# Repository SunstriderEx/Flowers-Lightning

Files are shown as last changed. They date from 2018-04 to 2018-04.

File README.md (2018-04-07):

# Подсветка растений
Умный светильник для комнатных растений и desktop-приложение для настройки устройства по USB.

Яркость светильника зависит от внешнего освещения, чем оно ярче, тем слабее он светит, поддерживая тем самым необходимый минимальный уровень освещённости.

## Подробности
Основной элемент - STM32 Minimum system development board.

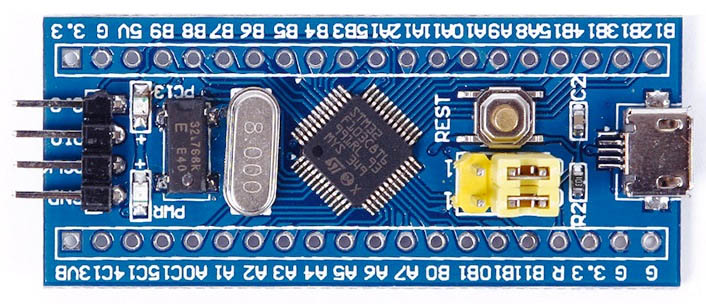
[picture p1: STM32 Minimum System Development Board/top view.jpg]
Внешний вид


На её борту имеется часовой кварцевый резонатор, что избавляет от необходимости отдельной установки данного компонента для работы RTC.

Для работы устройства необходим внешний блок питания на 12В и ток не менее 1А.

Использованный дроссель вводит ограничение на ток, протекающий через источник(и) света. В моём случае он составил около 1А. Хотя этот компонент является необязательным, так как пульсации на частоте 30 кГц незначительны.

В качестве датчика освещённости используется фоторезистор GL5528. Для регулировки зависимости яркости от внешнего освещения в устройстве присутствует подстроечный резистор.

Для настройки устройства используется приложение под Windows, позволяющее синхронизировать время часов и указывать время сна. Интерфейс связи - USB. Скриншот программы:

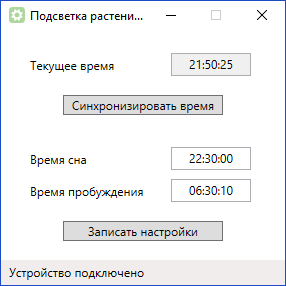
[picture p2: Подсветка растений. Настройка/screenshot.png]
Скриншот программы


При входе и выходе из режима сна яркость понижается или повышается медленно и плавно.

Для ручного перевода светильника в режим сна имеется соответствующая кнопка (устройство "проснётся" по графику).

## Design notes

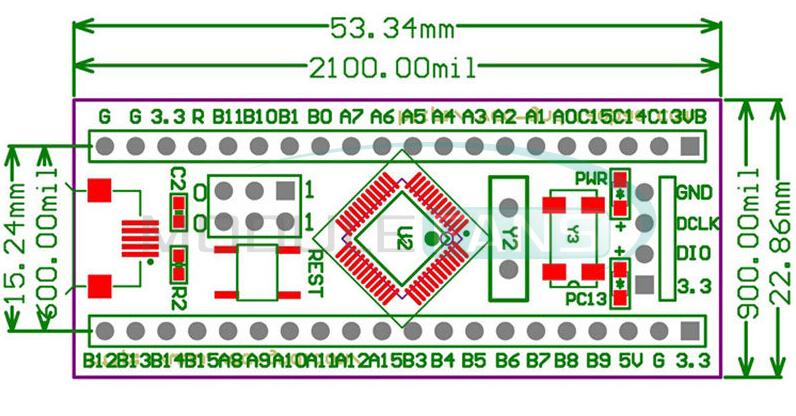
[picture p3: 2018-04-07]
STM32 Minimum System Development Board/dimensions.jpg

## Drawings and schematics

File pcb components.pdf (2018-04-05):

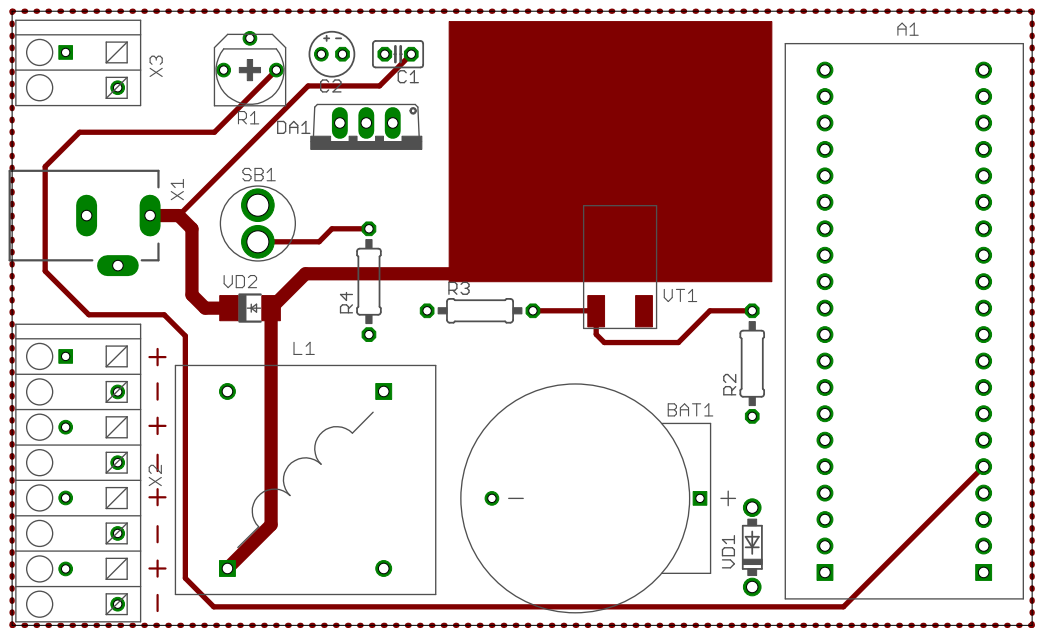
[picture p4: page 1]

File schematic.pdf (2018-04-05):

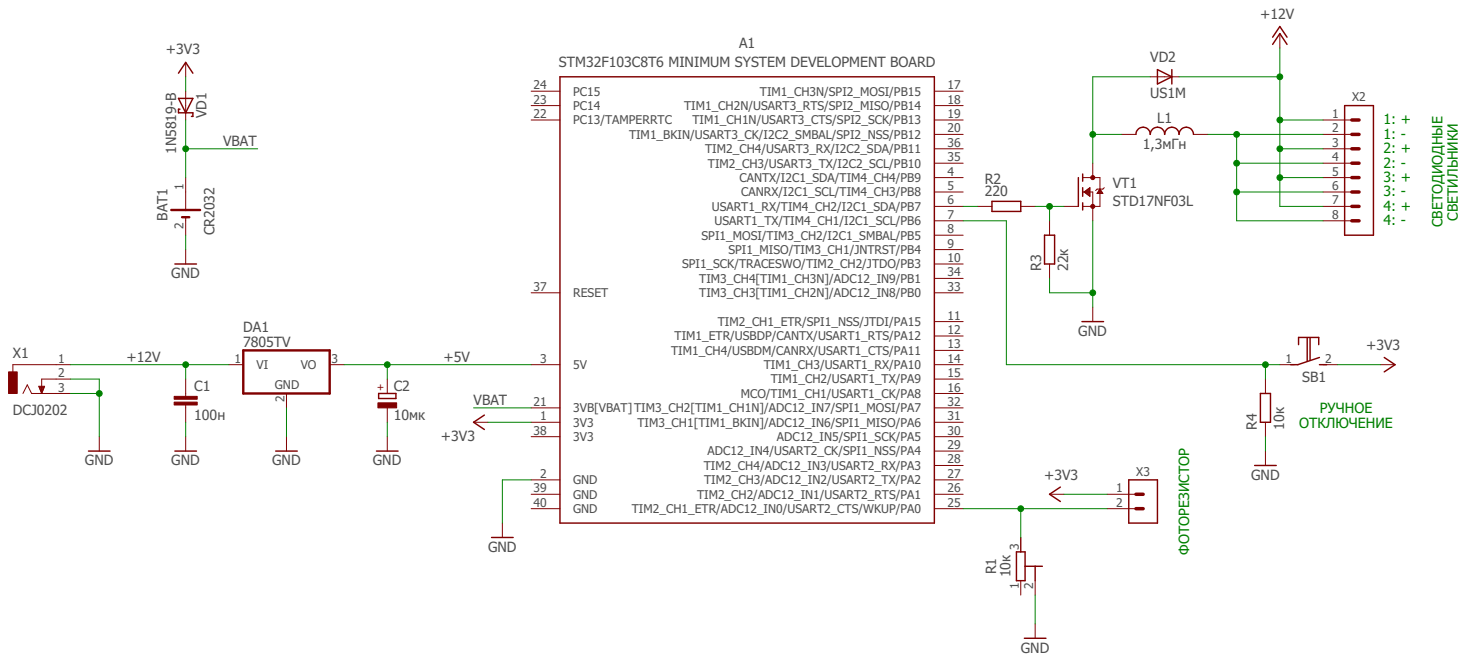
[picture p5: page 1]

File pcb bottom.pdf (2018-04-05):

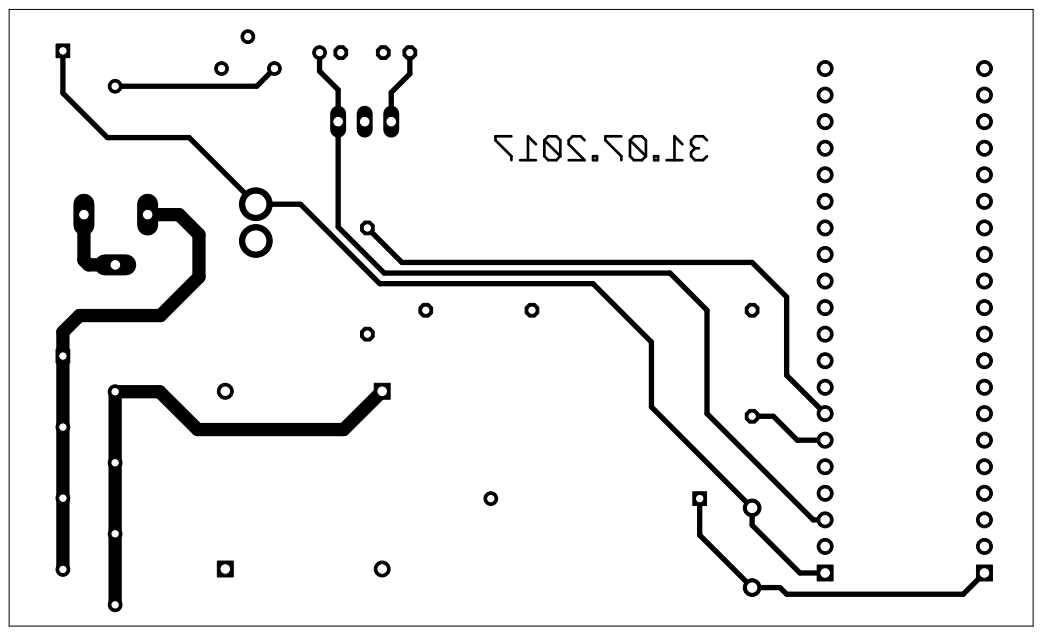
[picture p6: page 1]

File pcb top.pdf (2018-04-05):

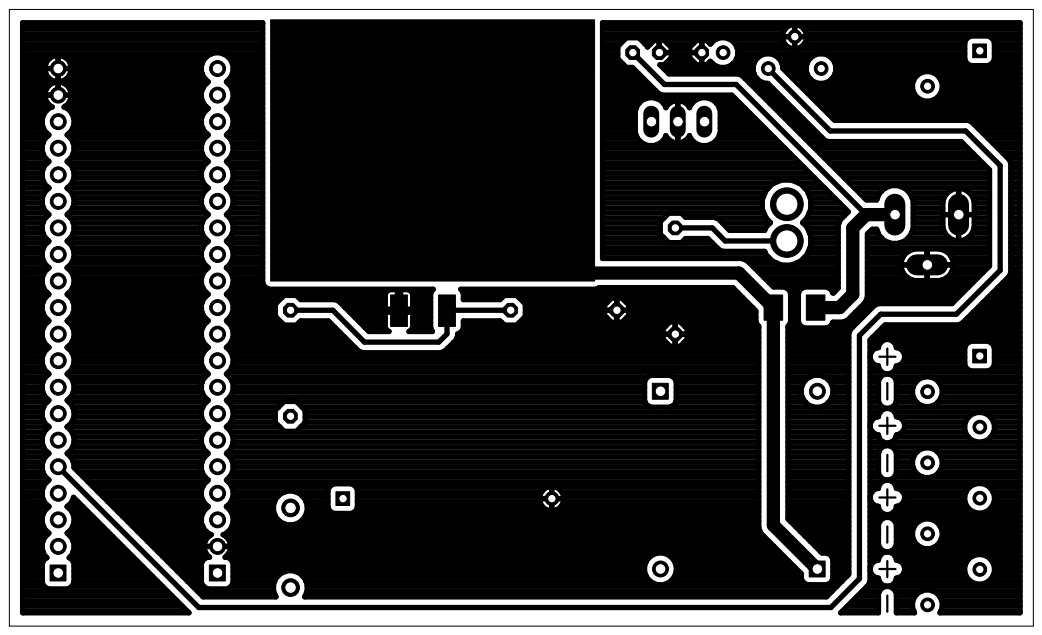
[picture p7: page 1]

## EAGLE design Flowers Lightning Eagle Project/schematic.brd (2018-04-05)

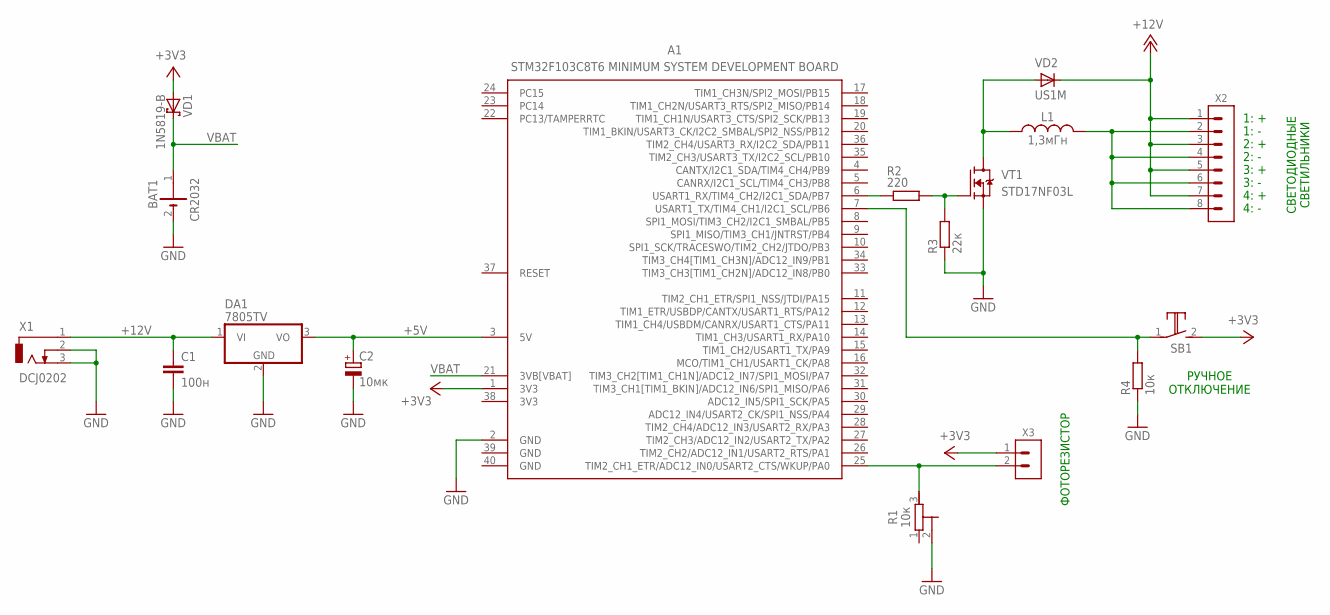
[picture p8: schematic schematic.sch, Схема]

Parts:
A1: STM32F103C8T6_MINIMUM_SYSTEM_DEVELOPMENT_BOARD
BAT1: CR2032; CR2032HOLDER
C1: 100н; C025-025X050
C2: 10мк; E2-4
DA1: 7805TV; TO220V
L1: 1,3мГн; INDUCTOR-2.5MH
R1: 10к; TRIMMER
R2: 220; 0207/10
R3: 22к; 0207/10
R4: 10к; 0207/10
SB1: PBS-10B-2
VD1: 1N5819-B; DO41-7.6
VD2: US1M; DO-214AC
VT1: STD17NF03L; DPAK
X1: DCJ0202
X2: TERMINALS_BLOCK_8PIN
X3: TERMINALS_BLOCK_2PIN

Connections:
3V3: A1.38 (3V3)
+3V3: A1.1 (3V3), SB1.2 (NO), VD1.A, X3.1
+5V: A1.3 (5V), C2.+, DA1.3 (VO)
+12V: C1.1, DA1.1 (VI), VD2.C, X1.1, X2.1, X2.3, X2.5, X2.7
DRAIN: L1.1, VD2.A, VT1.D
GND: A1.2 (GND), A1.39 (GND), A1.40 (GND), BAT1.2 (-), C1.2, C2.-, DA1.2 (GND), R1.2 (S), R3.1, R4.1, VT1.S, X1.2, X1.3
unnamed: A1.7 (USART1_TX/TIM4_CH1/I2C1_SCL/PB6), R4.2, SB1.1 (COM)
unnamed: R2.2, R3.2, VT1.G
unnamed: L1.2, X2.2, X2.4, X2.6, X2.8
unnamed: A1.25 (TIM2_CH1_ETR/ADC12_IN0/USART2_CTS/WKUP/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), R1.3 (E), X3.2
unnamed: A1.6 (USART1_RX/TIM4_CH2/I2C1_SDA/PB7), R2.1
VBAT: A1.21 (3VB[VBAT]), BAT1.1 (+), VD1.C

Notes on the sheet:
ФОТОРЕЗИСТОР
СВЕТОДИОДНЫЕ СВЕТИЛЬНИКИ
1: +
1: -
2: +
2: -
3: +
3: -
4: +
4: -
РУЧНОЕ ОТКЛЮЧЕНИЕ

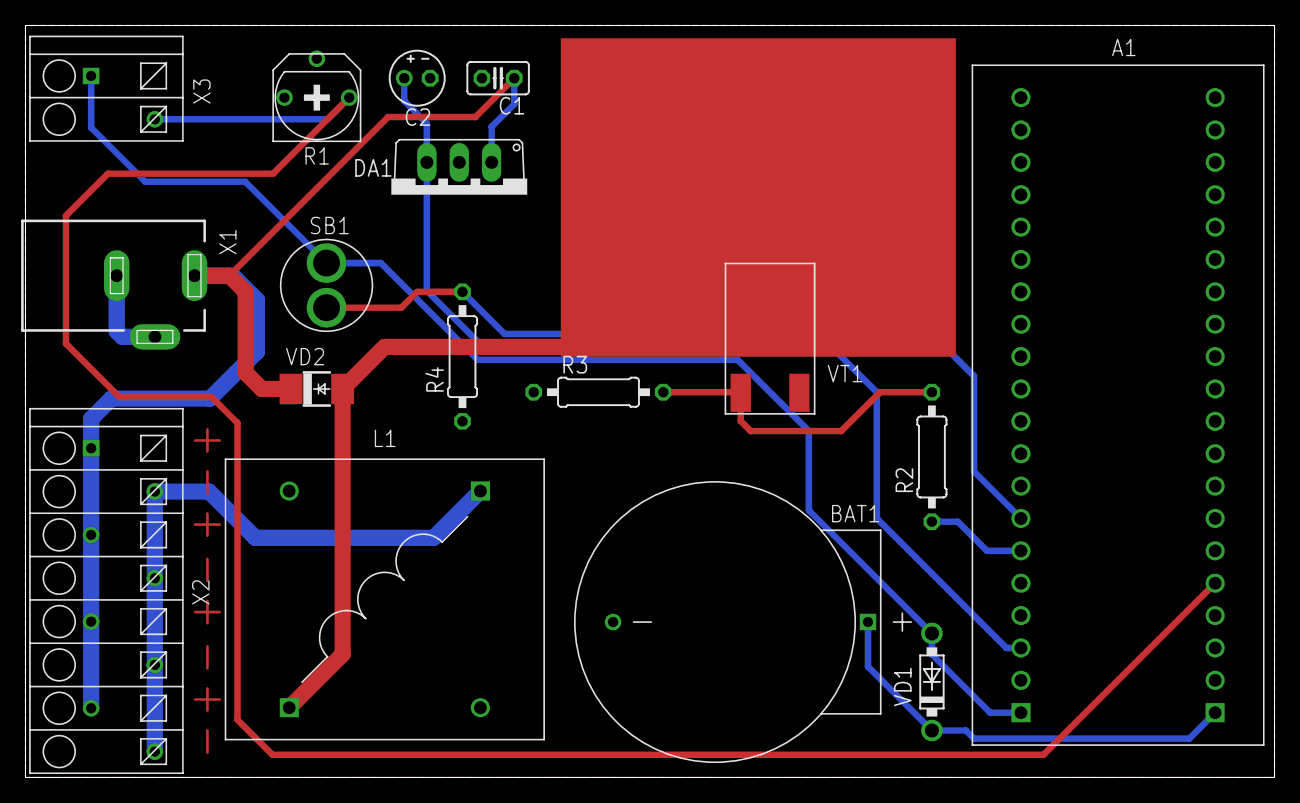
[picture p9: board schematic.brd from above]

Board: 2 copper layers, 98.0 x 59.0 mm, 17 parts (0 on the bottom side), 11 nets.

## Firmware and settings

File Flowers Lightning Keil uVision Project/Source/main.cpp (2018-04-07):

#include "stm32f10x.h"
#include "stm32f10x_gpio.h"
#include "stm32f10x_rcc.h"
#include "stm32f10x_usart.h"
#include "misc.h"

#include "adc.h"
#include "pwm.h"
#include "rtc.h"
#include "supply.h"
#include "usart.h"
#include "timing.h"
#include "usb hid.h"
#include "flash.h"

#include <math.h>
#include <stdio.h>

void SetSysClockTo72()
{
    ErrorStatus HSEStartUpStatus;
    /* SYSCLK, HCLK, PCLK2 and PCLK1 configuration -----------------------------*/
    /* RCC system reset(for debug purpose) */
    RCC_DeInit();
 
    /* Enable HSE */
    RCC_HSEConfig(RCC_HSE_ON);
 
    /* Wait till HSE is ready */
    HSEStartUpStatus = RCC_WaitForHSEStartUp();
 
    if (HSEStartUpStatus == SUCCESS)
    {
        /* Enable Prefetch Buffer */
        //FLASH_PrefetchBufferCmd( FLASH_PrefetchBuffer_Enable);
 
        /* Flash 2 wait state */
        //FLASH_SetLatency( FLASH_Latency_2);
 
        /* HCLK = SYSCLK */
        RCC_HCLKConfig(RCC_SYSCLK_Div1);
 
        /* PCLK2 = HCLK */
        RCC_PCLK2Config(RCC_HCLK_Div1);
 
        /* PCLK1 = HCLK/2 */
        RCC_PCLK1Config(RCC_HCLK_Div1);
 
        /* PLLCLK = 8MHz * 9 = 72 MHz */
        RCC_PLLConfig(0x00010000, RCC_PLLMul_9);
 
        /* Enable PLL */
        RCC_PLLCmd(ENABLE);
 
        /* Wait till PLL is ready */
        while (RCC_GetFlagStatus(RCC_FLAG_PLLRDY) == RESET)
        {
        }
 
        /* Select PLL as system clock source */
        RCC_SYSCLKConfig(RCC_SYSCLKSource_PLLCLK);
 
        /* Wait till PLL is used as system clock source */
        while (RCC_GetSYSCLKSource() != 0x08)
        {
        }
    }
    else
    { /* If HSE fails to start-up, the application will have wrong clock configuration.
     User can add here some code to deal with this error */
 
        /* Go to infinite loop */
        while (1)
        {
        }
    }
}

void Init()
{
    SetSysClockTo72();
    Timing::InitSysTickTimer();
    
    RCC_APB2PeriphClockCmd(RCC_APB2Periph_GPIOA, ENABLE); // Enable GPIOA clocking
    RCC_APB2PeriphClockCmd(RCC_APB2Periph_GPIOB, ENABLE); // Enable GPIOB clocking
    
    GPIO_InitTypeDef port;
    GPIO_StructInit(&port);
    port.GPIO_Mode = GPIO_Mode_IPD;
    port.GPIO_Pin = GPIO_Pin_6;
    port.GPIO_Speed = GPIO_Speed_2MHz;
    GPIO_Init(GPIOB, &port);
}

float ldrValue;
float duty = 1;

int main()
{
    Init();

    // Initialize USART
    //USART::Init();
    //USART::USARTSend((const unsigned char*)"Hello.\r\nUSART1 is ready.\r\n");
    USB_HID::Init(); // нужно инициализировать до RTCModule::Init(), иначе задержка не даст копму получить дескриптор
                     // (при подключении по USB без батарейки в устройстве, вероятно)    
    Flash::Init();
    
    ADC::Init();
    ADC::Calibrate();
    ADC::StartReading();
    
    PWM::Init();
    PWM::Enable();
 
    unsigned int RTC_Counter;
    unsigned int RTC_Counter_TimeToSleep;
    unsigned int RTC_Counter_TimeToAwake;
    RTC_TimeTypeDef RTC_Time;
    if (RTCModule::Init() == 1)
    {
        // После инициализации требуется задержка. Без нее время не устанавливается.
        osDelay(100);//for (int i = 0; i < 1000000; i++) { } //delay_ms(500);
        // Если первая инициализация RTC устанавливаем начальное время
        RTC_Time.hours = 15;
        RTC_Time.minutes = 29;
        RTC_Time.seconds = 55;
        RTC_SetCounter(RTCModule::TimeToCounter(&RTC_Time));
    }
    // Считаем настройки времени из Flash памяти
    Flash::ReadSettings();
    
    // usart
    //char buffer[80] = {'\0'};
    unsigned int lastRTC_Counter = 0;
    
    while (1)
    {
        // Real Time Clock
        RTC_Counter = RTC_GetCounter();
        RTCModule::CounterToTime(RTC_Counter, &RTC_Time);
        // Reset RTC every day
        if (RTC_Counter >= RTCModule::CounterToResetRTC)
        {
            RTCModule::ResetRTC();
            RTC_Counter = RTC_GetCounter();
            RTCModule::CounterToTime(RTC_Counter, &RTC_Time);
        }
        
        // Sleeping Mode
        RTC_Counter_TimeToSleep = RTCModule::TimeToCounter((RTC_TimeTypeDef*)(&RTCModule::TimeToSleep));
        RTC_Counter_TimeToAwake = RTCModule::TimeToCounter((RTC_TimeTypeDef*)(&RTCModule::TimeToAwake));
        if ((RTC_Counter >= RTC_Counter_TimeToSleep && RTC_Counter < RTC_Counter_TimeToAwake && RTC_Counter_TimeToAwake > RTC_Counter_TimeToSleep)
            || ((RTC_Counter >= RTC_Counter_TimeToSleep || RTC_Counter < RTC_Counter_TimeToAwake) && RTC_Counter_TimeToAwake < RTC_Counter_TimeToSleep))
        {
            
            if (!Supply::SleepingModeIsActive())
            {
                PWM::fadingModeIsActive = true; // плавное затухание
                Supply::StartSleepingMode(false);
            }
            else if (Supply::SleepingModeIsForced()) // если в сон вошли кнопкой, то сбрасываем флаг forcedSleepingMode, 
                Supply::StartSleepingMode(false);    // чтобы [утром] автоматически выйти из режима сна (проснуться)
        }
        else
        {
            if (Supply::SleepingModeIsActive() && !Supply::SleepingModeIsForced())
                Supply::AwakeFromSleepingMode();
        }
        
        // Force Sleeping Mode button
        Supply::CheckSleepingModeButton();
        
        // PWM
        if (!Supply::SleepingModeIsActive())
        {
            ldrValue = ADC::GetPhotoresistorValue(); // LDR (Light Dependent Resistor) = Photoresistor
            duty = powf((ldrValue / (4096 - 1)), 0.5); //, 0.25);
            PWM::UpdateDuty(duty);
        }
        else if (PWM::fadingModeIsActive)
        {
            // плавное затухание
            duty += 0.0000005;
            PWM::UpdateDuty(duty);
            if (duty > PWM::dimThreshold)
                Supply::StartSleepingMode(true); // окончательный сон
        }
        
        // USART and USB
        //USB_HID::CheckUSBConnection();
        //sprintf(buffer, "ldrValue = %d, duty = %f\r\n", ldrValue, duty);
        if (Timing::Millis() - lastRTC_Counter >= 200) //if (lastRTC_Counter != RTC_Counter)
        {
            //sprintf(buffer, "counter = %d, Time = %d:%d:%d, millis = %d\r\n", RTC_Counter, RTC_Time.hours, RTC_Time.minutes, RTC_Time.seconds, Timing::Millis());
            //USART::USARTSend((unsigned char*)buffer);
            
            //sprintf(buffer, "%d:%d:%d", RTC_Time.hours, RTC_Time.minutes, RTC_Time.seconds);
            //USBD_HID_GetReportTrigger(0, USB_HID::DeviceRtcTime, (const uint8_t*)(&buffer), sizeof(buffer));
            USB_HID::SendSettings();
            
            lastRTC_Counter = Timing::Millis(); //RTC_Counter;
        }
        
        // Save settings if needed
        Flash::WriteSettingsIfNeeded();
    }
}

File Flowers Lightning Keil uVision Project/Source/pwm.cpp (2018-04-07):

#include "pwm.h"

const float PWM::brightThreshold = 0.001;
const float PWM::dimThreshold = 0.999;
bool PWM::fadingModeIsActive;

extern "C" void TIM3_IRQHandler()
{
    if (TIM_GetITStatus(TIM3, TIM_IT_Update) != RESET)
    {
        TIM_ClearITPendingBit(TIM3, TIM_IT_Update);
        
        GPIOC->ODR ^= GPIO_Pin_13;
    }
}

void PWM::Init()
{
    RCC_APB1PeriphClockCmd(RCC_APB1Periph_TIM4, ENABLE);  // Enable TIM4 clocking
    
    GPIO_InitTypeDef port;
    TIM_TimeBaseInitTypeDef timer;
    TIM_OCInitTypeDef timerPWM;
 
    GPIO_StructInit(&port);
    port.GPIO_Mode = GPIO_Mode_AF_PP;
    port.GPIO_Pin = GPIO_Pin_7; // pin PB7
    port.GPIO_Speed = GPIO_Speed_2MHz;
    GPIO_Init(GPIOB, &port);
 
    TIM_TimeBaseStructInit(&timer);
    timer.TIM_Prescaler = 0;
    timer.TIM_Period = Period;
    timer.TIM_ClockDivision = 0; //TIM_CKD_DIV1;
    timer.TIM_CounterMode = TIM_CounterMode_Up;
    TIM_TimeBaseInit(TIM4, &timer);
 
    TIM_OCStructInit(&timerPWM);
    // PWM mode 2 = Clear on compare match
    // PWM mode 1 = Set on compare match
    timerPWM.TIM_OCMode = TIM_OCMode_PWM2;
    timerPWM.TIM_OutputState = TIM_OutputState_Enable;
    timerPWM.TIM_Pulse = Period - 1;
    timerPWM.TIM_OCPolarity = TIM_OCPolarity_High;
    TIM_OC2Init(TIM4, &timerPWM);
    
    //UpdateDuty(1);
    
    InitLED();
}

void PWM::Enable()
{
    GPIO_SetBits(GPIOC, GPIO_Pin_13); // Off LED
    TIM_Cmd(TIM4, ENABLE);
    TIM_Cmd(TIM3, ENABLE);
}

void PWM::Disable()
{
    TIM_Cmd(TIM4, DISABLE);
    TIM_Cmd(TIM3, DISABLE);
    UpdateDuty(1);
    GPIO_SetBits(GPIOC, GPIO_Pin_13); // Off LED
}

void PWM::UpdateDuty(float duty)
{
    /*To get proper duty cycle, you have simple equation
    
    pulse_length = ((TIM_Period + 1) * DutyCycle) / 100 - 1
    
    where DutyCycle is in percent, between 0 and 100%
    
    25% duty cycle:     pulse_length = ((8399 + 1) * 25) / 100 - 1 = 2099
    50% duty cycle:     pulse_length = ((8399 + 1) * 50) / 100 - 1 = 4199
    75% duty cycle:     pulse_length = ((8399 + 1) * 75) / 100 - 1 = 6299
    100% duty cycle:    pulse_length = ((8399 + 1) * 100) / 100 - 1 = 8399
    
    Remember: if pulse_length is larger than TIM_Period, you will have output HIGH all the time*/
    
    if (duty > dimThreshold)
        duty = 1.0;
    else if (duty < brightThreshold)
        duty = 0;
    
    duty = (Period + 1) * duty - 1;
    
    TIM4->CCR2 = duty;

    //TIM3->PSC = duty * 10 + 1000; // prescaler (Indicator LED)
}

void PWM::InitLED()
{
    RCC_APB1PeriphClockCmd(RCC_APB1Periph_TIM3, ENABLE);  // Enable TIM3 clocking
    RCC_APB2PeriphClockCmd(RCC_APB2Periph_GPIOC, ENABLE); // Enable PORTC Clock
    
    // Initialize LED which connected to PC13
    GPIO_InitTypeDef  GPIO_InitStructure;
    // Configure the GPIO_LED pin
    GPIO_InitStructure.GPIO_Pin = GPIO_Pin_13;
    GPIO_InitStructure.GPIO_Mode = GPIO_Mode_Out_PP;
    GPIO_InitStructure.GPIO_Speed = GPIO_Speed_2MHz;
    GPIO_Init(GPIOC, &GPIO_InitStructure);
 
    GPIO_SetBits(GPIOC, GPIO_Pin_13); // Off LED
    
    //
    TIM_TimeBaseInitTypeDef timer;
    TIM_TimeBaseStructInit(&timer);
    timer.TIM_Prescaler = 10000;
    timer.TIM_Period = Period;
    timer.TIM_ClockDivision = 0;
    timer.TIM_CounterMode = TIM_CounterMode_Up;
    TIM_TimeBaseInit(TIM3, &timer);
 
    TIM_OCInitTypeDef timerOC;
    TIM_OCStructInit(&timerOC);
    timerOC.TIM_OCMode = TIM_OCMode_PWM2;
    timerOC.TIM_OutputState = TIM_OutputState_Enable;
    timerOC.TIM_Pulse = 50;
    timerOC.TIM_OCPolarity = TIM_OCPolarity_High;
    TIM_OC1Init(TIM3, &timerOC);
    
    // NVIC Configuration
    // Enable the TIM3_IRQn Interrupt
    NVIC_InitTypeDef NVIC_InitStructure;
    NVIC_InitStructure.NVIC_IRQChannel = TIM3_IRQn;
    NVIC_InitStructure.NVIC_IRQChannelPreemptionPriority = 0;
    NVIC_InitStructure.NVIC_IRQChannelSubPriority = 0;
    NVIC_InitStructure.NVIC_IRQChannelCmd = ENABLE;
    NVIC_Init(&NVIC_InitStructure);
    
    
    TIM_ITConfig(TIM3, TIM_IT_Update, ENABLE);
}

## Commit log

2018-04-05 Files upload
    [schematic.brd, schematic.sch]
2018-04-07 STM32 board data
